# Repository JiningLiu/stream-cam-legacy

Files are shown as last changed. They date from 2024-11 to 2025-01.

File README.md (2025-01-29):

# RPi Streaming Camera

> ❗We are working on an improved version of stream-cam. This repository is now a public archive.

> ⚠️ More info will be available at [JiningLiu/stream-cam](https://github.com/JiningLiu/stream-cam/) soon.

## Hardware

You will need:

- Raspberry Pi 5 2GB
- 32GB microSD Card
- Pi 5 Active Cooler
- Pi 5 Power Supply
- Raspberry Pi Camera Module 3
- Pi 5 Camera Ribbon Cable
- Router (only need one for all cameras)

...and the following:

- 4pcs M2 10mm
- 4pcs M2 nut
- 4pcs M2.5 10mm
- 4pcs M2.5 nut
- 4pcs M4 10mm
- 1pc 1/4-20 UNC nut
- 2pcs small zip/cable ties

Download the 3MF file located in the [hardware](./hardware) directory 3D print the parts.

Put together the setup according to the [assembly instructions](./hardware/ASSEMBLY.md).

## Software

### Installation

Use the [Raspberry Pi Imager](https://www.raspberrypi.com/software/) to flash SD card with [Raspberry Pi OS](https://www.raspberrypi.com/software/operating-systems/) (64-bit) with desktop ([version used for this release](https://downloads.raspberrypi.com/raspios_arm64/images/raspios_arm64-2024-07-04/2024-07-04-raspios-bookworm-arm64.img.xz))
- Setup SSH in Raspberry Pi Imager settings.
- Setup the Wi-Fi (wireless LAN) network that the Pi will be streaming video over.
  - This network should have access to the internet for initial setup. Alternatively, use ethernet or another Wi-Fi network with internet access, and setup the streaming network later.

Connect your computer to the same network you have just configured for the Pi. Then, plug in the Pi and wait a few minutes for initial setup to complete.

Use SSH to connect to the Pi with the credentials you have setup earlier. If you are unable to connect to the Pi over Wi-Fi, try using ethernet.

#### Follow these steps to finish setup.

Note that the commands below will take a bit of time to run.

```bash
sudo raspi-config
```
- Turn on VNC
- Set boot/login options to desktop (auto login)

```bash
sudo apt update
sudo apt upgrade
sudo apt install vim

curl -sL https://raw.githubusercontent.com/nvm-sh/nvm/v0.40.1/install.sh | bash
source ~/.bashrc

nvm install --lts

echo "alias serve='cd ~/stream-cam-web && npm run preview & cd ~/stream-overlays && bun run preview & node ~/stream-cam-legacy/server/index.js'" >> ~/.bashrc
echo "alias cam='~/stream-cam-legacy/mediamtx'" >> ~/.bashrc
echo "alias web='cd stream-cam-web && npm run preview'" >> ~/.bashrc
echo "alias overlays='cd stream-overlays && bun run preview'" >> ~/.bashrc
echo "alias stop='killall node & killall vite & killall mediamtx & killall bun & lsof -ti :3000 :5281 :6232 | xargs kill
'" >> ~/.bashrc
echo "alias update='~/stream-cam-legacy/update.sh'" >> ~/.bashrc
source ~/.bashrc

cd ~/
git clone https://github.com/JiningLiu/stream-cam-legacy/
cd stream-cam-legacy
chmod +x update.sh
cd server
cp ./mediamtx.yml ~/mediamtx.yml
npm i

cd ~/
git clone https://github.com/JiningLiu/stream-cam-web/
cd stream-cam-web
npm i
npm run build

npm install -g bun

cd ~/
git clone https://github.com/JiningLiu/stream-overlays/
cd stream-overlays
bun i
bun run build

echo "serve" >> ~/.bashrc

sudo reboot
```

Your Pi will now reboot, and automatically start the server when it's on.

If you had previously used ethernet to connect to the Pi, or was using a different network not meant for streaming, you can now use VNC to access the GUI, and add the Wi-Fi network that you would like to use for video transmission.

Your Pi is now ready for live streaming!

### Updating

In order to update the software on your camera to the latest minor version on the major release installed, simply run `update` in the terminal of the Pi.

If you would like to upgrade your camera to a newer major release, you will need to wipe your Pi and reinstall the software.

## Licenses

© 2024 Jining Liu, [MIT License](./LICENSE)

### Credits

[bluenviron/mediamtx](https://github.com/bluenviron/mediamtx)

© 2019 aler9, [MIT License](https://github.com/bluenviron/mediamtx/blob/main/LICENSE)

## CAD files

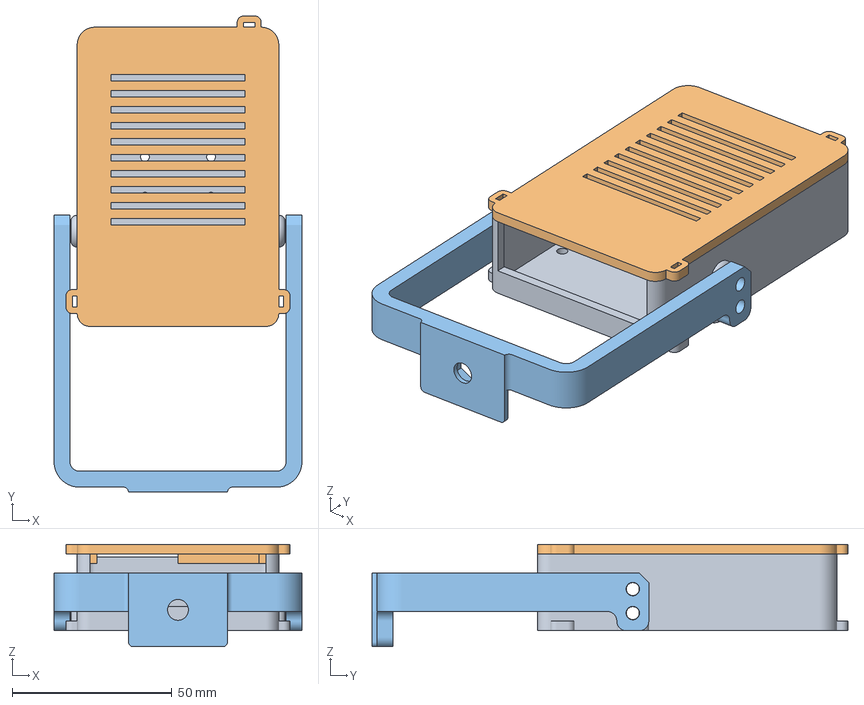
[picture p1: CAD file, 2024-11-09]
hardware/Pi Cam Case.3mf
77.5 x 148.8 x 32.0 mm
Case
Lid
Stand

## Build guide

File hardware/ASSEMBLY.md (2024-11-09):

# Assembly Instructions

Detailed instructions coming soon.

### Steps

1. Put together Raspberry Pi & accessories, plug the camera into port 0.
2. With the case flat side down, insert M2 screws into the 4 holes in the middle of the casing. On the other side, put the camera on and secure with M2 nuts.
    - The cable/connector of the camera should point upwards, toward the short side of the casing with only 1 zip/cable tie hole.
3. Put the Pi into the casing, and insert M2.5 screws into the 4 mounting holes on the Pi and through the outer holes on the case. Secure with M2.5 nuts on the other side.
4. Insert 1/4-20 UNC nut into hexagonal hole on the stand (tripod adapter), then mount the adapter onto the casing with M4 screws through the 4 holes on the side of the casing.
5. Fit the top ventilation lid over the casing.
6. Insert zip/cable ties into the 2 set of holes on the long side of the case and lid near where the stand (tripod adapter) is. Wrap the zip/cable ties around each of the 2 legs of the stand (tripod adapter). Pull until slightly tight.

🎉 **Assembly finished!** The 2 zip/cable ties acts as a hinge when the tripod adapter is not screwed on, allowing the ventilation lid to be rotated open. The other hole can be used to secure the lid down and prevent the lid from being opened.

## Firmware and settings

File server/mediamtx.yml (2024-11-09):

###############################################
# Global settings

# Settings in this section are applied anywhere.

###############################################
# Global settings -> General

# Verbosity of the program; available values are "error", "warn", "info", "debug".
logLevel: info
# Destinations of log messages; available values are "stdout", "file" and "syslog".
logDestinations: [stdout]
# If "file" is in logDestinations, this is the file which will receive the logs.
logFile: mediamtx.log

# Timeout of read operations.
readTimeout: 10s
# Timeout of write operations.
writeTimeout: 10s
# Size of the queue of outgoing packets.
# A higher value allows to increase throughput, a lower value allows to save RAM.
writeQueueSize: 512
# Maximum size of outgoing UDP packets.
# This can be decreased to avoid fragmentation on networks with a low UDP MTU.
udpMaxPayloadSize: 1472

# Command to run when a client connects to the server.
# This is terminated with SIGINT when a client disconnects from the server.
# The following environment variables are available:
# * RTSP_PORT: RTSP server port
# * MTX_CONN_TYPE: connection type
# * MTX_CONN_ID: connection ID
runOnConnect:
# Restart the command if it exits.
runOnConnectRestart: no
# Command to run when a client disconnects from the server.
# Environment variables are the same of runOnConnect.
runOnDisconnect:

###############################################
# Global settings -> Authentication

# Authentication method. Available values are:
# * internal: users are stored in the configuration file
# * http: an external HTTP URL is contacted to perform authentication
# * jwt: an external identity server provides authentication through JWTs
authMethod: internal

# Internal authentication.
# list of users.
authInternalUsers:
  # Default unprivileged user.
  # Username. 'any' means any user, including anonymous ones.
- user: any
  # Password. Not used in case of 'any' user.
  pass:
  # IPs or networks allowed to use this user. An empty list means any IP.
  ips: []
  # List of permissions.
  permissions:
    # Available actions are: publish, read, playback, api, metrics, pprof.
  - action: publish
    # Paths can be set to further restrict access to a specific path.
    # An empty path means any path.
    # Regular expressions can be used by using a tilde as prefix.
    path:
  - action: read
    path:
  - action: playback
    path:

  # Default administrator.
  # This allows to use API, metrics and PPROF without authentication,
  # if the IP is localhost.
- user: any
  pass:
  ips: ['127.0.0.1', '::1']
  permissions:
  - action: api
  - action: metrics
  - action: pprof

# HTTP-based authentication.
# URL called to perform authentication. Every time a user wants
# to authenticate, the server calls this URL with the POST method
# and a body containing:
# {
#   "user": "user",
#   "password": "password",
#   "ip": "ip",
#   "action": "publish|read|playback|api|metrics|pprof",
#   "path": "path",
#   "protocol": "rtsp|rtmp|hls|webrtc|srt",
#   "id": "id",
#   "query": "query"
# }
# If the response code is 20x, authentication is accepted, otherwise
# it is discarded.
authHTTPAddress:
# Actions to exclude from HTTP-based authentication.
# Format is the same as the one of user permissions.
authHTTPExclude:
- action: api
- action: metrics
- action: pprof

# JWT-based authentication.
# Users have to login through an external identity server and obtain a JWT.
# This JWT must contain the claim "mediamtx_permissions" with permissions,
# for instance:
# {
#  ...
#  "mediamtx_permissions": [
#     {
#       "action": "publish",
#       "path": "somepath"
#     }
#   ]
# }
# Users are expected to pass the JWT in the Authorization header or as a query parameter.
# This is the JWKS URL that will be used to pull (once) the public key that allows
# to validate JWTs.
authJWTJWKS:

###############################################
# Global settings -> Control API

# Enable controlling the server through the Control API.
api: no
# Address of the Control API listener.
apiAddress: :9997
# Enable TLS/HTTPS on the Control API server.
apiEncryption: no
# Path to the server key. This is needed only when encryption is yes.
# This can be generated with:
# openssl genrsa -out server.key 2048
# openssl req -new -x509 -sha256 -key server.key -out server.crt -days 3650
apiServerKey: server.key
# Path to the server certificate.
apiServerCert: server.crt
# Value of the Access-Control-Allow-Origin header provided in every HTTP response.
apiAllowOrigin: '*'
# List of IPs or CIDRs of proxies placed before the HTTP server.
# If the server receives a request from one of these entries, IP in logs
# will be taken from the X-Forwarded-For header.
apiTrustedProxies: []

###############################################
# Global settings -> Metrics
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

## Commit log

2024-11-09 updated cad file & assembly instructions
    [Pi Cam Case.3mf]
2024-11-09 updated camera settings
